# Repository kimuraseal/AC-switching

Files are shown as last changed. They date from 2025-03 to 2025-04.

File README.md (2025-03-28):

# 4CH AC, 2CH DC Switching and ZCD
The circuit consist of 
- Four optoisolated TRIAC switching circuit.
  Two channels being zero cross switched and other two being random phase switched.
- Two optoisolated MOSFET switching circuit.
  Capable of High speed operations.
- Zero Cross Detector.

# 4CH AC、2CH DC スイッチングおよびZCD
この回路は以下の構成になっています。
- 光アイソレーション付きTRIACスイッチング回路（4系統）
  2つはゼロクロススイッチング
  2つはランダムフェーズスイッチング
- 光アイソレーション付きMOSFETスイッチング回路（2系統）
  高速動作が可能
- ゼロクロス検出回路

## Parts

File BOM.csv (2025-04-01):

Country of Origin may be different at time of shipment.
The HTSUS and ECCN information shown is for informational purposes only and is not a representation or warranty as to the accuracy or reliability of these classifications. All information is provided "as is" and is subject to change without notice. Any use made of the information provided is without recourse to Digi-Key and at the user's risk.
Index | Manufacturer Part Number | Manufacturer Name | Description | Availability | Stock Status | Attrition % | Requested Quantity 1 | Pack Quantity 1 | Pack Type 1 | Digi-Key Part Number 1 | Unit Price 1 | Extended Price 1 | Minimum Order Quantity 1 | Customer Reference | Requested Part Number | Lead Weeks | Datasheet | Reference Designator | US Import Tariff | Note | Part Status | RoHS Status | REACH Status | Moisture Sensitivity Level (MSL) | ECCN | HTSUS | Country of Origin | Environmental Information | Original Part numbers | Unit of Measure | Image | Product Notes
1 | G800W268018EU | Amphenol ICC (Commercial Products) | PIN HEADER 2.54MM PITCH STR,1X40 | 1,288 | In Stock |  | 2 | 2 | Bag | 664-G800W268018EU-ND | 99.00000 | ¥198 | 1 |  | G800W268018EU | 10 | https://cdn.amphenol-cs.com/media/wysiwyg/files/drawing/g800wxxxxxxeu_1.pdf |  | - |  | Active | ROHS3 Compliant |  | Not Applicable | EAR99 | 8536.69.4040 | China |  | G800W268018EU | EACH | https://mm.digikey.com/Volume0/opasdata/d220001/derivates/6/001/148/493/G800W268018EU_web%28640x640%29.jpg
2 | PZT3904T1G | onsemi | TRANS NPN 40V 0.2A SOT223 | 21,926 | In Stock |  | 20 | 20 | Cut Tape (CT) | PZT3904T1GOSCT-ND | 55.40000 | ¥1,108 | 1 |  | PZT3904T1G | 14 | https://www.onsemi.com/pdf/datasheet/pzt3904t1-d.pdf |  | - |  | Active | ROHS3 Compliant | REACH Unaffected | 1 (Unlimited) | EAR99 | 8541.29.0075 | Malaysia | https://www.onsemi.com/site/pdf/RoHS-statement.pdf|https://www.onsemi.com/PowerSolutions/MaterialComposition.do?export=pdf&opnId=PZT3904T1G | SPZT3904T1G | EACH | https://mm.digikey.com/Volume0/opasdata/d220001/medias/images/6285/488%7E318E-04%7EST%7E4.jpg
3 | TLV1117-33CDCYR | Texas Instruments | IC REG LIN 3.3V 800MA SOT-223-4 | 9,822 | In Stock |  | 3 | 3 | Cut Tape (CT) | 296-21112-1-ND | 63.00000 | ¥189 | 1 |  | TLV1117-33CDCYR | 6 | https://www.ti.com/general/docs/suppproductinfo.tsp?distId=10 |  | - |  | Active | ROHS3 Compliant | REACH Unaffected | 2 (1 Year) | EAR99 | 8542.39.0060 | China |  | NCP1117ST33T3G | EACH | https://mm.digikey.com/Volume0/opasdata/d220001/medias/images/6222/296%7E4202506%7EDCY%7E4.jpg
4 | 691137710002 | Würth Elektronik | TERM BLK 2POS SIDE ENTRY 5MM PCB | 20,290 | In Stock |  | 12 | 12 | Box | 732-10955-ND | 51.20000 | ¥614 | 1 |  | 691137710002 | 19 | https://www.we-online.com/katalog/datasheet/691137710002.pdf |  | - |  | Active | ROHS3 Compliant | REACH Unaffected | Not Applicable | EAR99 | 8536.90.4000 | Italy | https://mm.digikey.com/Volume0/opasdata/d220001/medias/docus/744/Certificate_of_Compliance_ROHS.pdf | 6.91138E+11 | EACH | https://mm.digikey.com/Volume0/opasdata/d220001/medias/images/2284/MFG_691137710002_View2.jpg
5 | T1635-600G-TR | STMicroelectronics | TRIAC ALTERNISTOR 600V 16A D2PAK | 40,354 | In Stock |  | 10 | 10 | Cut Tape (CT) | 497-6594-1-ND | 169.40000 | ¥1,694 | 1 |  | T1635-600G-TR | 15 | https://www.st.com/content/ccc/resource/technical/document/datasheet/67/06/bc/c9/35/8e/4f/ea/CD00002265.pdf/files/CD00002265.pdf/jcr:content/translations/en.C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 |  | - |  | Active | ROHS3 Compliant | REACH Unaffected | 1 (Unlimited) | EAR99 | 8541.30.0080 | China |  | T1635-600G-TR | EACH | https://mm.digikey.com/Volume0/opasdata/d220001/medias/images/2435/D%C2%B2Pak%2CTO-263_418AA-01.jpg
6 | MOC3052M | onsemi | OPTOISOLTR 4.17KV TRIAC 1CH 6DIP | 5,330 | In Stock |  | 6 | 6 | Tube | MOC3052M-ND | 168.00000 | ¥1,008 | 1 |  | MOC3052M-ND | 8 | https://www.onsemi.com/pdf/datasheet/moc3052m-d.pdf |  | - |  | Active | ROHS3 Compliant | REACH Unaffected | Not Applicable | EAR99 | 8541.49.8000 | Thailand | https://www.onsemi.com/site/pdf/RoHS-statement.pdf|https://www.onsemi.com/PowerSolutions/MaterialComposition.do?export=pdf&opnId=MOC3052M | MOC3052M-ND | EACH | https://mm.digikey.com/Volume0/opasdata/d220001/medias/images/2438/46-6-DIP%20WHITE.jpg
7 | MOC3062M | onsemi | OPTOISOLTR 4.17KV TRIAC 1CH 6DIP | 3,921 | In Stock |  | 6 | 6 | Tube | MOC3062M-ND | 202.00000 | ¥1,212 | 1 |  | MOC3062M | 8 | https://www.onsemi.com/pdf/datasheet/moc3163m-d.pdf |  | - |  | Active | ROHS3 Compliant | REACH Unaffected | Not Applicable | EAR99 | 8541.49.8000 | South Korea | https://www.onsemi.com/site/pdf/RoHS-statement.pdf|https://www.onsemi.com/PowerSolutions/MaterialComposition.do?export=pdf&opnId=MOC3062M | MOC3062M | EACH | https://mm.digikey.com/Volume0/opasdata/d220001/medias/images/969/MOC3062M.JPG
8 | ERZ-V10D201 | Panasonic Electronic Components | VARISTOR 200V 3.5KA DISC 11.5MM | 2,210 | In Stock |  | 10 | 10 | Bulk | P7205-ND | 66.50000 | ¥665 | 1 |  | ERZ-V10D201 | 18 | https://industrial.panasonic.com/ww/products/pt/surge-components/models/ERZV10D201 |  | - |  | Active | ROHS3 Compliant | REACH Unaffected | Not Applicable | EAR99 | 8533.40.4000 | Indonesia |  | ERZ-V10D201 | EACH | https://mm.digikey.com/Volume0/opasdata/d220001/medias/images/2403/D10%2C%2014%20V%20Series.jpg
9 | B32682A6222K000 | EPCOS - TDK Electronics | CAP FILM 2200PF 10% 630VDC RAD | 1,836 | In Stock |  | 10 | 10 | Bulk | 495-7310-ND | 89.10000 | ¥891 | 1 |  | B32682A6222K000 | 10 | https://product.tdk.com/en/system/files |  | - |  | Active | ROHS3 Compliant | REACH Unaffected | Not Applicable | EAR99 | 8532.25.0070 | China | https://www.tdk-electronics.tdk.com/download/2078174/66ff23f8bbbac65cb7b31f8fa69f2b53/reach-rohs-declaration.pdf|https://www.tdk-electronics.tdk.com/en/180310/company/sustainability/environmental-protection/reach | B32682A6222K000 | EACH | https://mm.digikey.com/Volume0/opasdata/d220001/medias/images/909/B32682-Series.jpg
10 | RC1206FR-10150RL | YAGEO | RES 150 OHM 1% 1/4W 1206 | 18,000 | In Stock |  | 30 | 30 | Cut Tape (CT) | 13-RC1206FR-10150RLCT-ND | 3.00000 | ¥90 | 1 |  | RC1206FR-10150RL | 18 | https://www.yageo.com/upload/media/product/products/datasheet/rchip/PYu-RC_Group_51_RoHS_L_12.pdf |  | - |  | Active | ROHS3 Compliant | REACH Unaffected | 1 (Unlimited) | EAR99 | 8533.21.0030 | Taiwan | https://www.yageo.com/en/Download/Index/certificates#rchip | RC1206FR-10150RL | EACH | https://mm.digikey.com/Volume0/opasdata/d220001/medias/images/4842/Yageo-0603.jpg
11 | RC1206FR-10390RL | YAGEO | RES 390 OHM 1% 1/4W 1206 | 5,525 | In Stock |  | 30 | 30 | Cut Tape (CT) | 13-RC1206FR-10390RLCT-ND | 6.40000 | ¥192 | 1 |  | RC1206FR-10390RL | 18 | https://www.yageo.com/upload/media/product/products/datasheet/rchip/PYu-RC_Group_51_RoHS_L_12.pdf |  | - |  | Active | ROHS3 Compliant | REACH Unaffected | 1 (Unlimited) | EAR99 | 8533.21.0030 | Taiwan | https://www.yageo.com/en/Download/Index/certificates#rchip | RC1206FR-10390RL | EACH | https://mm.digikey.com/Volume0/opasdata/d220001/medias/images/4842/Yageo-0603.jpg
12 | RC1218JK-0751RL | YAGEO | RES 51 OHM 5% 1W 1812 WIDE | 7,379 | In Stock |  | 10 | 10 | Cut Tape (CT) | 13-RC1218JK-0751RLCT-ND | 22.50000 | ¥225 | 1 |  | RC1218JK-0751RL | 18 | https://www.yageo.com/upload/media/product/products/datasheet/rchip/PYu-RC_Group_51_RoHS_L_12.pdf |  | - |  | Active | ROHS3 Compliant | REACH Unaffected | 1 (Unlimited) | EAR99 | 8533.21.0030 | Taiwan | https://www.yageo.com/en/Download/Index/certificates#rchip | RC1218JK-0751RL | EACH | https://mm.digikey.com/Volume0/opasdata/d220001/medias/images/2289/Yageo-RC1218.jpg
13 | TLP250H(D4,F) | Toshiba Semiconductor and Storage | OPTOISO 3.75KV PUSH PULL 8-DIP | 438 | In Stock |  | 10 | 10 | Tube | TLP250H(D4F)-ND | 288.00000 | ¥2,880 | 1 |  | TLP250H(D4 F) | 12 | https://toshiba.semicon-storage.com/info/docget.jsp?did=13872&prodName=TLP250H |  | - |  | Active | ROHS3 Compliant | REACH Unaffected | Not Applicable | EAR99 | 8541.49.8000 | Japan |  | TLP250H(D4 F) | EACH | https://mm.digikey.com/Volume0/opasdata/d220001/medias/images/56/264%7E11-10C4%7E%7E8.jpg
14 | 4N35M | onsemi | OPTOISO 4.17KV TRANS W/BASE 6DIP | 4,296 | In Stock |  | 3 | 3 | Tube | 4N35MFS-ND | 103.00000 | ¥309 | 1 |  | 4N35MFS-ND | 8 | https://www.onsemi.com/pdf/datasheet/4n37m-d.pdf |  | - |  | Active | ROHS3 Compliant | REACH Unaffected | Not Applicable | EAR99 | 8541.49.8000 | Thailand | https://www.onsemi.com/site/pdf/RoHS-statement.pdf|https://www.onsemi.com/PowerSolutions/MaterialComposition.do?export=pdf&opnId=4N35M | 4N35MFS-ND | EACH | https://mm.digikey.com/Volume0/opasdata/d220001/medias/images/2438/46-6-DIP%20WHITE.jpg
15 | MDB6S | onsemi | BRIDGE RECT 1P 600V 1A 4MICRODIP | 29,697 | In Stock |  | 3 | 3 | Cut Tape (CT) | MDB6SFSCT-ND | 114.00000 | ¥342 | 1 |  | MDB6S | 18 | https://rocelec.widen.net/view/pdf/1nay6ifuuk/FAIRS45620-1.pdf?t.download=true&u=5oefqw |  | - |  | Active | ROHS3 Compliant | REACH Unaffected | 1 (Unlimited) | EAR99 | 8541.10.0080 | China | https://www.onsemi.com/site/pdf/RoHS-statement.pdf|https://www.onsemi.com/site/pdf/REACH-compliance-statement.pdf|https://www.onsemi.com/PowerSolutions/MaterialComposition.do?export=pdf&opnId=MDB6S | MDB6S | EACH | https://mm.digikey.com/Volume0/opasdata/d220001/medias/images/538/MDB6S.JPG
16 | SM5063 | Diotec Semiconductor | DIODE STANDARD 1000V 2A DO213AB | 4,598 | In Stock |  | 10 | 10 | Cut Tape (CT) | 4878-SM5063CT-ND | 27.10000 | ¥271 | 1 |  | SM5063 | 8 | https://diotec.com/request/datasheet/sm5059.pdf |  | - |  | Active | ROHS3 Compliant |  | 1 (Unlimited) | EAR99 | 8541.10.0080 | Slovenia | https://diotec.com/request/imds/p9_e.pdf | SM5063 | EACH | https://mm.digikey.com/Volume0/opasdata/d220001/derivates/6/003/224/470/MFG_4878%7EDO213AB%28MELF%29%7E%7E2_web%28640x640%29.jpg
17 | BZD27C10P-M3-08 | Vishay General Semiconductor - Diodes Division | DIODE ZENER 10V 800MW DO219AB | 11,700 | In Stock |  | 10 | 10 | Cut Tape (CT) | 112-BZD27C10P-M3-08CT-ND | 32.40000 | ¥324 | 1 |  | BZD27C10P-M3-08 | 16 | https://mm.digikey.com/Volume0/opasdata/d220001/medias/docus/2143/BZD27-M_Series.pdf |  | - |  | Active | ROHS3 Compliant | REACH Unaffected | 1 (Unlimited) | EAR99 | 8541.10.0050 | China |  | BZD27C10P-M3-08 | EACH | https://mm.digikey.com/Volume0/opasdata/d220001/medias/images/5789/112%7EDO219AB%28SMF%29%7E%7E2-View-2.jpg
18 | 50YXJ33M5X11 | Rubycon | CAP ALUM 33UF 20% 50V RADIAL TH | 5,178 | In Stock |  | 10 | 10 | Bulk | 1189-2323-ND | 29.70000 | ¥297 | 1 |  | 50YXJ33M5X11 | 20 | https://www.rubycon.co.jp/wp-content/uploads/catalog-aluminum/YXJ.pdf |  | - |  | Active | ROHS3 Compliant | REACH Unaffected | Not Applicable | EAR99 | 8532.22.0020 | Indonesia |  | 50YXF10MEFC5X11 | EACH | https://mm.digikey.com/Volume0/opasdata/d220001/medias/images/2595/YXJ%20Series%205x11.jpg
19 | B32529C6102M289 | EPCOS - TDK Electronics | CAP FILM 1000PF 20% 400VDC RAD | 15,998 | In Stock |  | 3 | 3 | Cut Tape (CT) | 495-B32529C6102M289CT-ND | 50.00000 | ¥150 | 1 |  | B32529C6102M289 | 7 | https://product.tdk.com/en/system/files |  | - |  | Active | ROHS3 Compliant | REACH Unaffected | Not Applicable | EAR99 | 8532.25.0070 | Brazil | https://www.tdk-electronics.tdk.com/download/2078174/66ff23f8bbbac65cb7b31f8fa69f2b53/reach-rohs-declaration.pdf|https://www.tdk-electronics.tdk.com/en/180310/company/sustainability/environmental-protection/reach | B32529C6102M289 | EACH | https://mm.digikey.com/Volume0/opasdata/d220001/medias/images/2586/MKT%20SERIES%208.0H%2C7.2L.jpg
20 | LTST-C150KGKT | Lite-On Inc. | LED GREEN CLEAR 1206 SMD | 368,310 | In Stock |  | 15 | 15 | Cut Tape (CT) | 160-1404-1-ND | 19.60000 | ¥294 | 1 |  | LTST-C150KGKT | 18 | https://optoelectronics.liteon.com/upload/download/DS22-2000-072/LTST-C150KGKT.pdf |  | - |  | Active | ROHS3 Compliant | REACH Unaffected | 3 (168 Hours) | EAR99 | 8541.41.0000 | China |  | LTST-C150KGKT | EACH | https://mm.digikey.com/Volume0/opasdata/d220001/medias/images/1055/LTST-C150TBKT%2CLTST-C150KAKT%2CLTST-C150KGKT.jpg
21 | LTST-C150KRKT | Lite-On Inc. | LED RED CLEAR 1206 SMD | 122,314 | In Stock |  | 15 | 15 | Cut Tape (CT) | 160-1405-1-ND | 19.60000 | ¥294 | 1 |  | LTST-C150KRKT | 18 | https://optoelectronics.liteon.com/upload/download/DS-22-99-0149/LTST-C150KRKT.pdf |  | - |  | Active | ROHS3 Compliant | REACH Unaffected | 3 (168 Hours) | EAR99 | 8541.41.0000 | China |  | LTST-C150KRKT | EACH | https://mm.digikey.com/Volume0/opasdata/d220001/medias/images/1062/LTST-C150KRKT%2CLTST-C150KSKT%2CLTST-C150KYKT.jpg
22 | RC1206FR-10180RL | YAGEO | RES 180 OHM 1% 1/4W 1206 | 25,517 | In Stock |  | 30 | 30 | Cut Tape (CT) | 13-RC1206FR-10180RLCT-ND | 6.40000 | ¥192 | 1 |  | RC1206FR-10180RL | 18 | https://www.yageo.com/upload/media/product/products/datasheet/rchip/PYu-RC_Group_51_RoHS_L_12.pdf |  | - |  | Active | ROHS3 Compliant | REACH Unaffected | 1 (Unlimited) | EAR99 | 8533.21.0030 | Taiwan | https://www.yageo.com/en/Download/Index/certificates#rchip | RC1206FR-10180RL | EACH | https://mm.digikey.com/Volume0/opasdata/d220001/medias/images/4842/Yageo-0603.jpg
23 | RC1206FR-10100RL | YAGEO | RES 100 OHM 1% 1/4W 1206 | 34,982 | In Stock |  | 30 | 30 | Cut Tape (CT) | 13-RC1206FR-10100RLCT-ND | 3.00000 | ¥90 | 1 |  | RC1206FR-10100RL | 18 | https://www.yageo.com/upload/media/product/products/datasheet/rchip/PYu-RC_Group_51_RoHS_L_12.pdf |  | - |  | Active | ROHS3 Compliant | REACH Unaffected | 1 (Unlimited) | EAR99 | 8533.21.0030 | Taiwan | https://www.yageo.com/en/Download/Index/certificates#rchip | RC1206FR-10100RL | EACH | https://mm.digikey.com/Volume0/opasdata/d220001/medias/images/4842/Yageo-0603.jpg
24 | RC1206FR-101KL | YAGEO | RES 1K OHM 1% 1/4W 1206 | 11,207 | In Stock |  | 10 | 10 | Cut Tape (CT) | 13-RC1206FR-101KLCT-ND | 3.00000 | ¥30 | 1 |  | RC1206FR-101KL | 18 | https://www.yageo.com/upload/media/product/products/datasheet/rchip/PYu-RC_Group_51_RoHS_L_12.pdf |  | - |  | Active | ROHS3 Compliant | REACH Unaffected | 1 (Unlimited) | EAR99 | 8533.21.0030 | Taiwan | https://www.yageo.com/en/Download/Index/certificates#rchip | RC1206FR-101KL | EACH | https://mm.digikey.com/Volume0/opasdata/d220001/medias/images/4842/Yageo-0603.jpg
25 | RC1206FR-103K3L | YAGEO | RES 3.3K OHM 1% 1/4W 1206 | 21,215 | In Stock |  | 10 | 10 | Cut Tape (CT) | 13-RC1206FR-103K3LCT-ND | 2.20000 | ¥22 | 1 |  | RC1206FR-103K3L | 18 | https://www.yageo.com/upload/media/product/products/datasheet/rchip/PYu-RC_Group_51_RoHS_L_12.pdf |  | - |  | Active | ROHS3 Compliant | REACH Unaffected | 1 (Unlimited) | EAR99 | 8533.21.0030 | Taiwan | https://www.yageo.com/en/Download/Index/certificates#rchip | RC1206FR-103K3L | EACH | https://mm.digikey.com/Volume0/opasdata/d220001/medias/images/4842/Yageo-0603.jpg
26 | RC1206FR-1010KL | YAGEO | RES 10K OHM 1% 1/4W 1206 | 28,383 | In Stock |  | 10 | 10 | Cut Tape (CT) | 13-RC1206FR-1010KLCT-ND | 3.30000 | ¥33 | 1 |  | RC1206FR-1010KL | 18 | https://www.yageo.com/upload/media/product/products/datasheet/rchip/PYu-RC_Group_51_RoHS_L_12.pdf |  | - |  | Active | ROHS3 Compliant | REACH Unaffected | 1 (Unlimited) | EAR99 | 8533.21.0030 | Taiwan | https://www.yageo.com/en/Download/Index/certificates#rchip | RC1206FR-1010KL | EACH | https://mm.digikey.com/Volume0/opasdata/d220001/medias/images/4842/Yageo-0603.jpg
27 | RC1206FR-1047KL | YAGEO | RES 47K OHM 1% 1/4W 1206 | 26,145 | In Stock |  | 10 | 10 | Cut Tape (CT) | 13-RC1206FR-1047KLCT-ND | 3.00000 | ¥30 | 1 |  | RC1206FR-1047KL | 18 | https://www.yageo.com/upload/media/product/products/datasheet/rchip/PYu-RC_Group_51_RoHS_L_12.pdf |  | - |  | Active | ROHS3 Compliant | REACH Unaffected | 1 (Unlimited) | EAR99 | 8533.21.0030 | Taiwan | https://www.yageo.com/en/Download/Index/certificates#rchip | RC1206FR-1047KL | EACH | https://mm.digikey.com/Volume0/opasdata/d220001/medias/images/4842/Yageo-0603.jpg
28 | 691137710003 | Würth Elektronik | TERM BLK 3POS SIDE ENTRY 5MM PCB | 1,757 | In Stock |  | 10 | 10 | Box | 732-10956-ND | 82.50000 | ¥825 | 1 |  | 691137710003 | 19 | https://www.we-online.com/katalog/datasheet/691137710003.pdf |  | - |  | Active | ROHS3 Compliant | REACH Unaffected | Not Applicable | EAR99 | 8536.90.4000 | Italy | https://mm.digikey.com/Volume0/opasdata/d220001/medias/docus/744/Certificate_of_Compliance_ROHS.pdf | 6.91138E+11 | EACH | https://mm.digikey.com/Volume0/opasdata/d220001/medias/images/2357/MFG_691137710003_View2.jpg
29 | RC1218JK-07100RL | YAGEO | RES 100 OHM 5% 1W 1812 WIDE | 9,047 | In Stock |  | 10 | 10 | Cut Tape (CT) | 13-RC1218JK-07100RLCT-ND | 14.70000 | ¥147 | 1 |  | RC1218JK-07100RL | 18 | https://www.yageo.com/upload/media/product/products/datasheet/rchip/PYu-RC_Group_51_RoHS_L_12.pdf |  | - |  | Active | ROHS3 Compliant | REACH Unaffected | 1 (Unlimited) | EAR99 | 8533.21.0030 | Taiwan |  | RC1218JK-07100RL | EACH | https://mm.digikey.com/Volume0/opasdata/d220001/medias/images/2289/Yageo-RC1218.jpg | Non Cancellable Non Returnable.
30 | STD7NK40ZT4 | STMicroelectronics | MOSFET N-CH 400V 5.4A DPAK | 4,690 | In Stock |  | 10 | 10 | Cut Tape (CT) | 497-6565-1-ND | 215.60000 | ¥2,156 | 1 |  | STD7NK40ZT4 | 13 | https://www.st.com/content/ccc/resource/technical/document/datasheet/67/d1/ab/b4/95/b0/4c/33/CD00003040.pdf/files/CD00003040.pdf/jcr:content/translations/en.C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 |  | - |  | Active | ROHS3 Compliant | REACH Unaffected | 1 (Unlimited) | EAR99 | 8541.29.0095 | China |  | STD7NK40ZT4 | EACH | https://mm.digikey.com/Volume0/opasdata/d220001/medias/images/6256/497%7EDPAK%28TO252-3%29%7E%7E2.jpg
31 | NC191LT10 | Chip Quik Inc. | SMOOTH FLOW LOW TEMP SOLDER PAST | 74 | In Stock |  | 1 | 1 | Bulk | 315-NC191LT10-ND | 1,245.00000 | ¥1,245 | 1 |  | NC191LT10 | 4 | http://www.chipquik.com/datasheets/NC191LT10.pdf |  | - |  | Active | ROHS3 Compliant | REACH Unaffected | 1 (Unlimited) | EAR99 | 3810.10.0000 | Canada |  | NC191LT10 | EACH | https://mm.digikey.com/Volume0/opasdata/d220001/medias/images/57/MFG_NC191LT10.jpg
32 | NC191 | Chip Quik Inc. | SMOOTH FLOW TACK FLUX NO-CLEAN I | 555 | In Stock |  | 1 | 1 | Bulk | 315-NC191-ND | 1,558.00000 | ¥1,558 | 1 |  | NC191 | 4 | http://www.chipquik.com/datasheets/NC191.pdf |  | - |  | Active | ROHS3 Compliant | REACH Unaffected | 1 (Unlimited) | EAR99 | 3810.10.0000 | Canada |  | NC191 | EACH | https://mm.digikey.com/Volume0/opasdata/d220001/medias/images/57/MFG_NC191.jpg

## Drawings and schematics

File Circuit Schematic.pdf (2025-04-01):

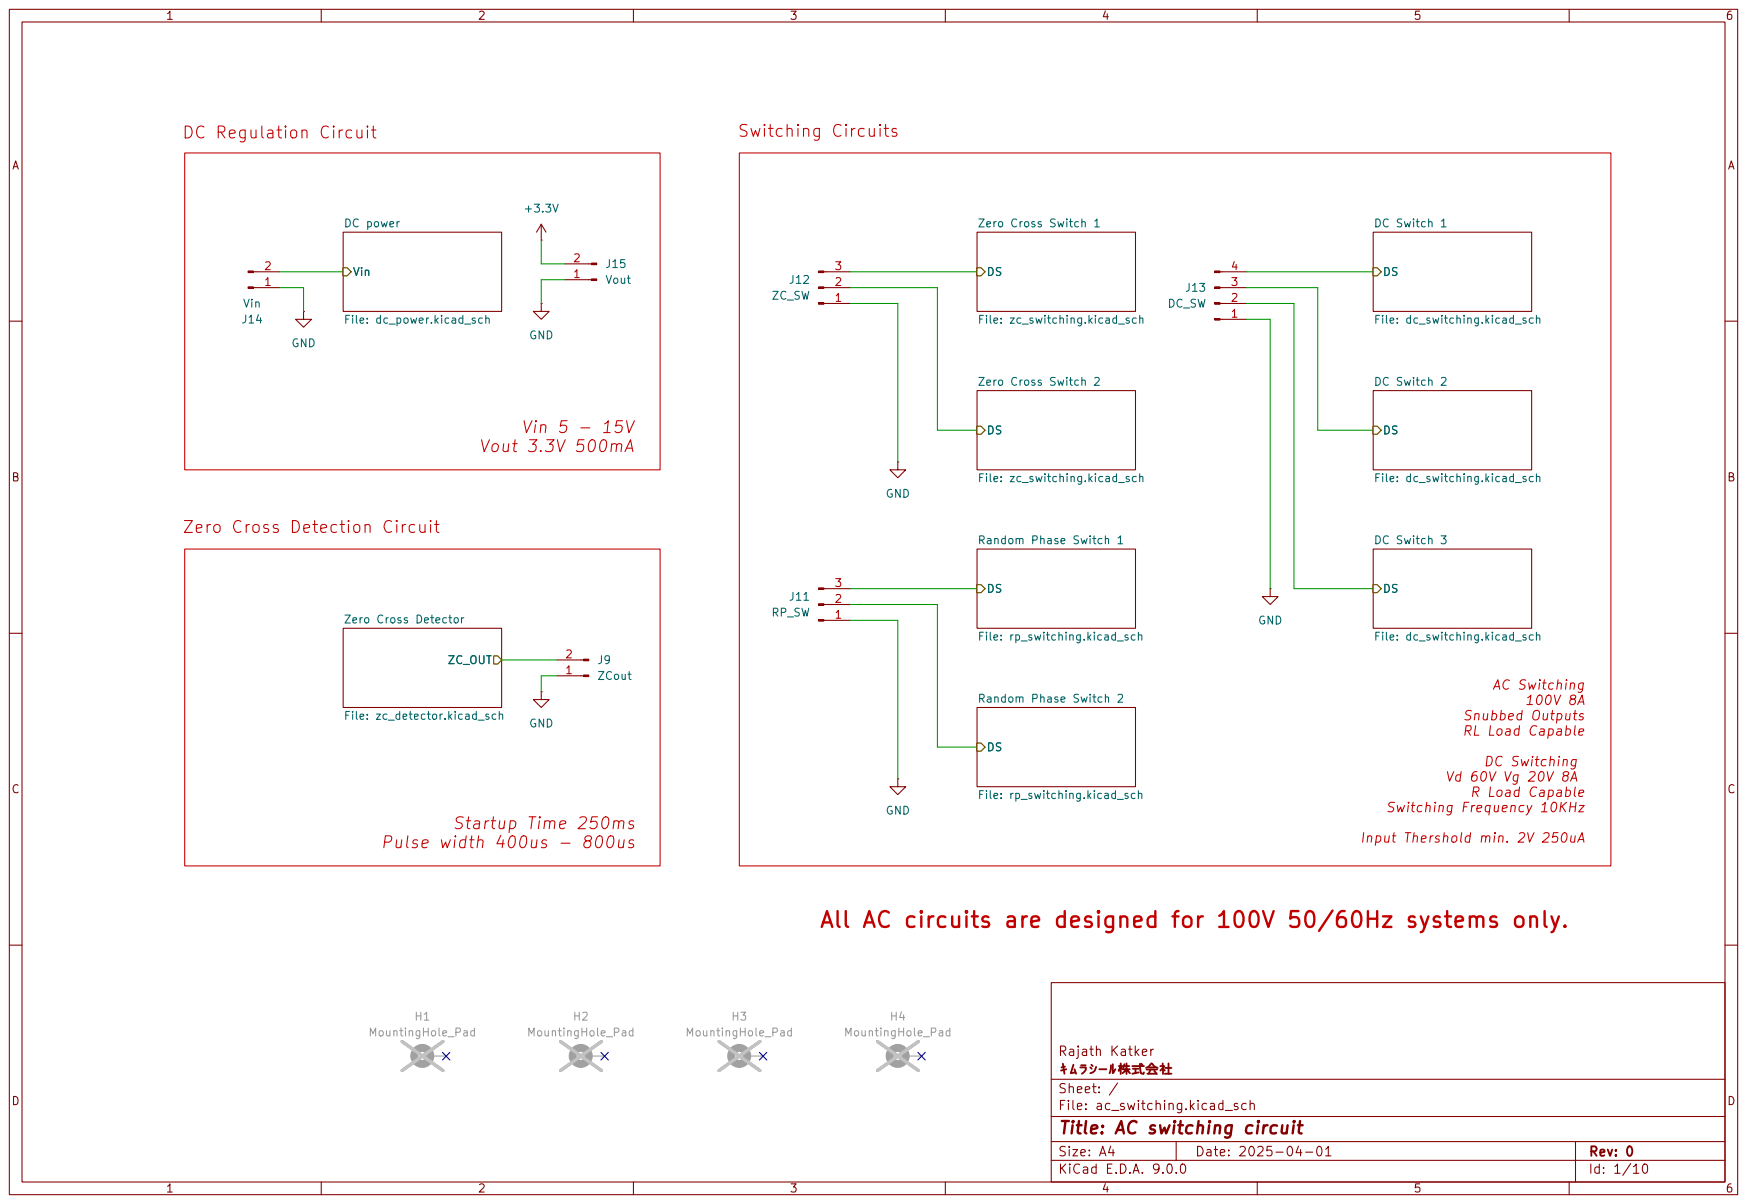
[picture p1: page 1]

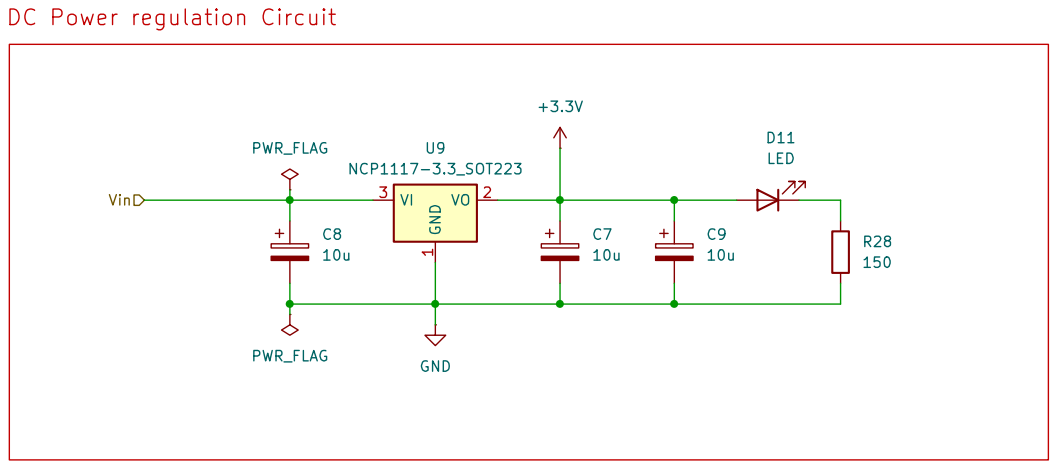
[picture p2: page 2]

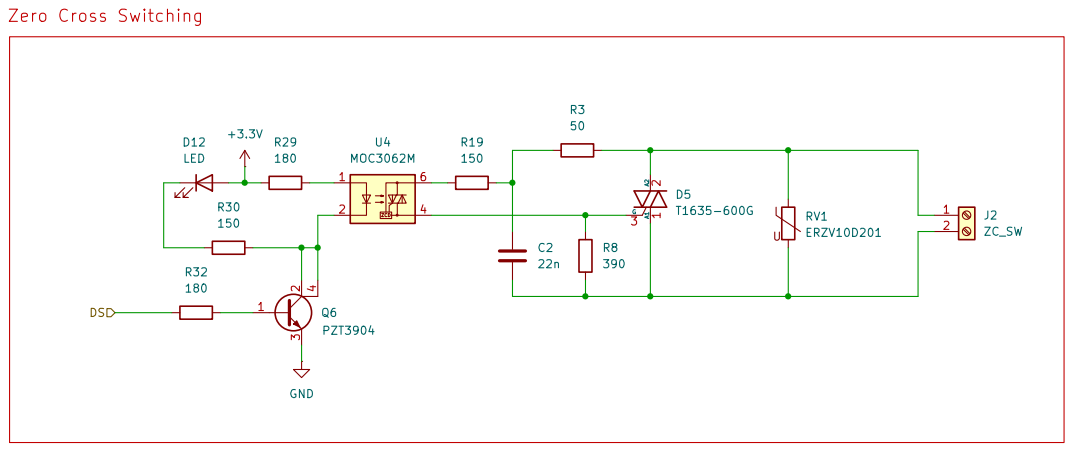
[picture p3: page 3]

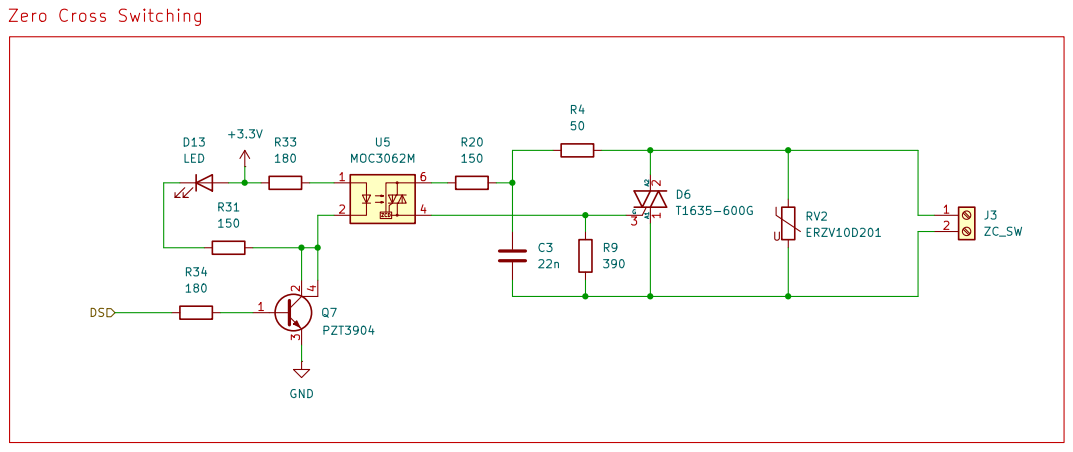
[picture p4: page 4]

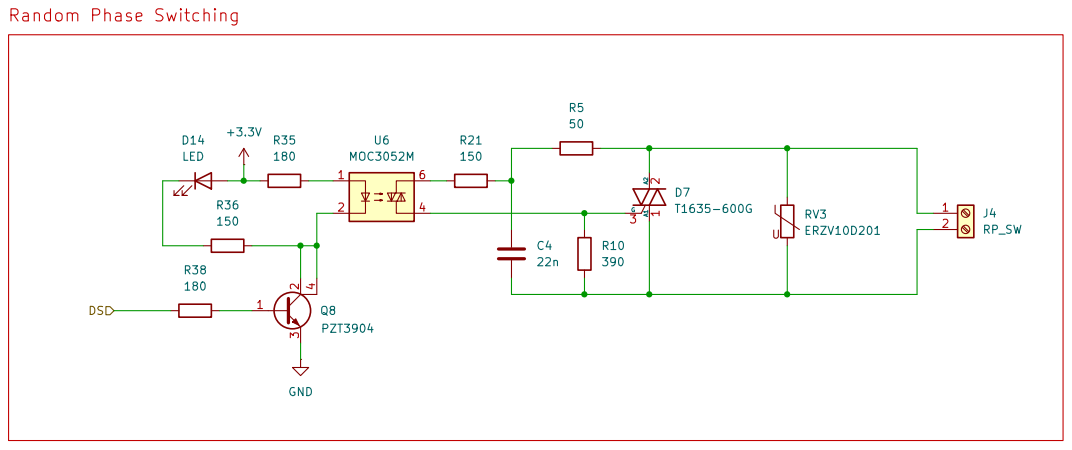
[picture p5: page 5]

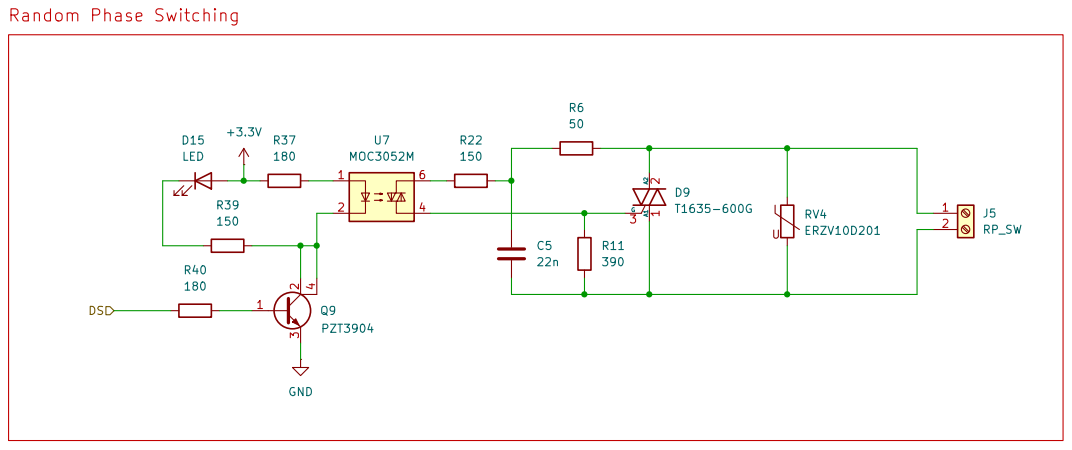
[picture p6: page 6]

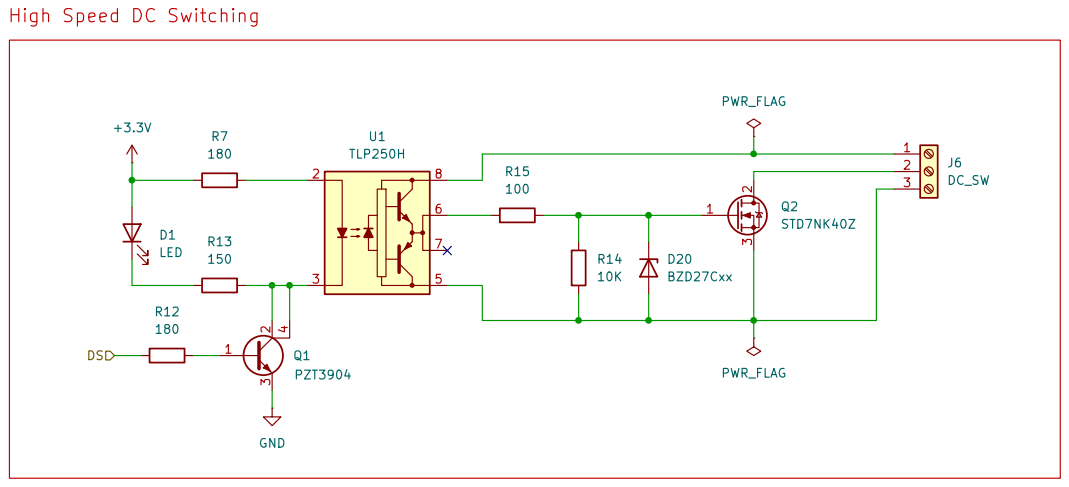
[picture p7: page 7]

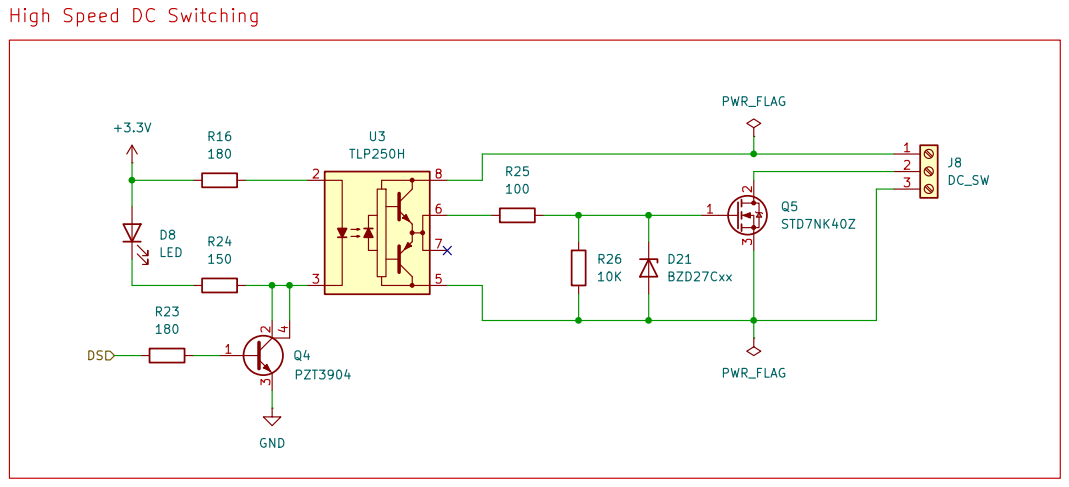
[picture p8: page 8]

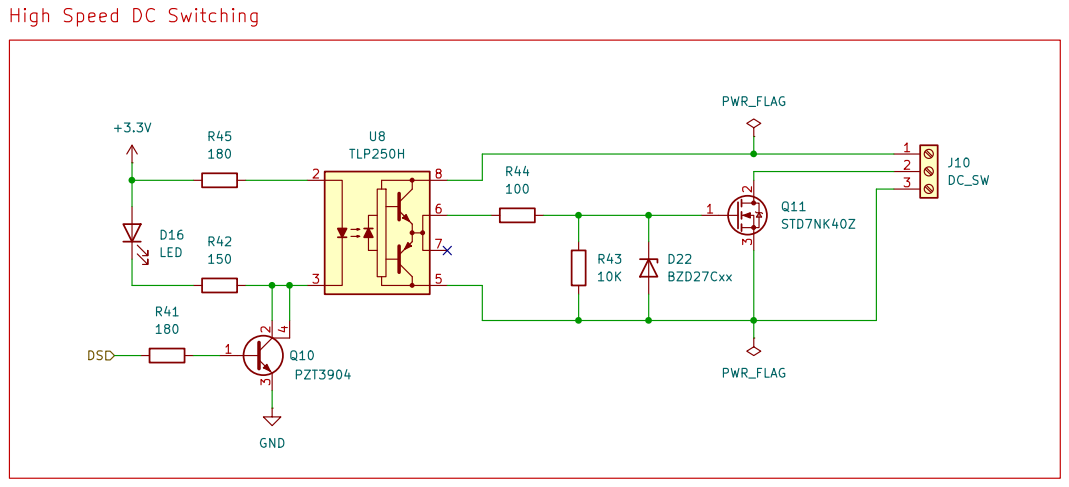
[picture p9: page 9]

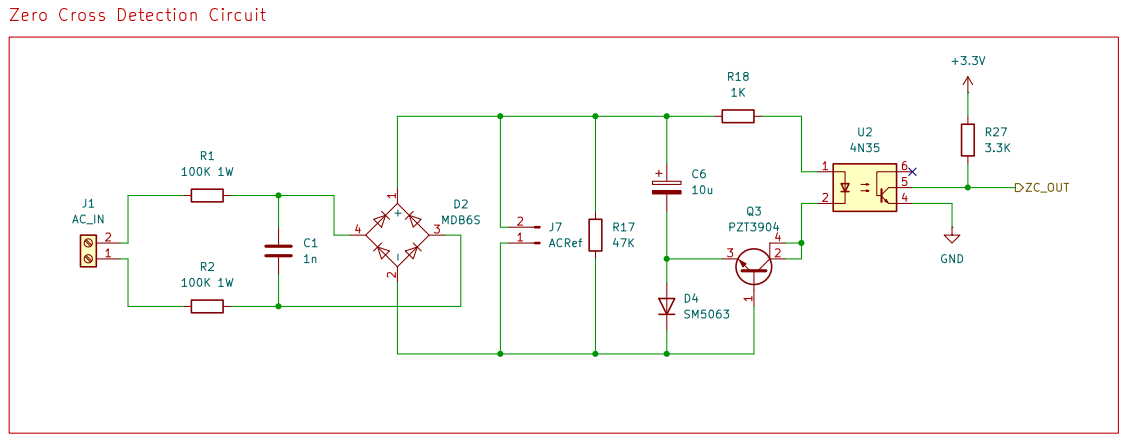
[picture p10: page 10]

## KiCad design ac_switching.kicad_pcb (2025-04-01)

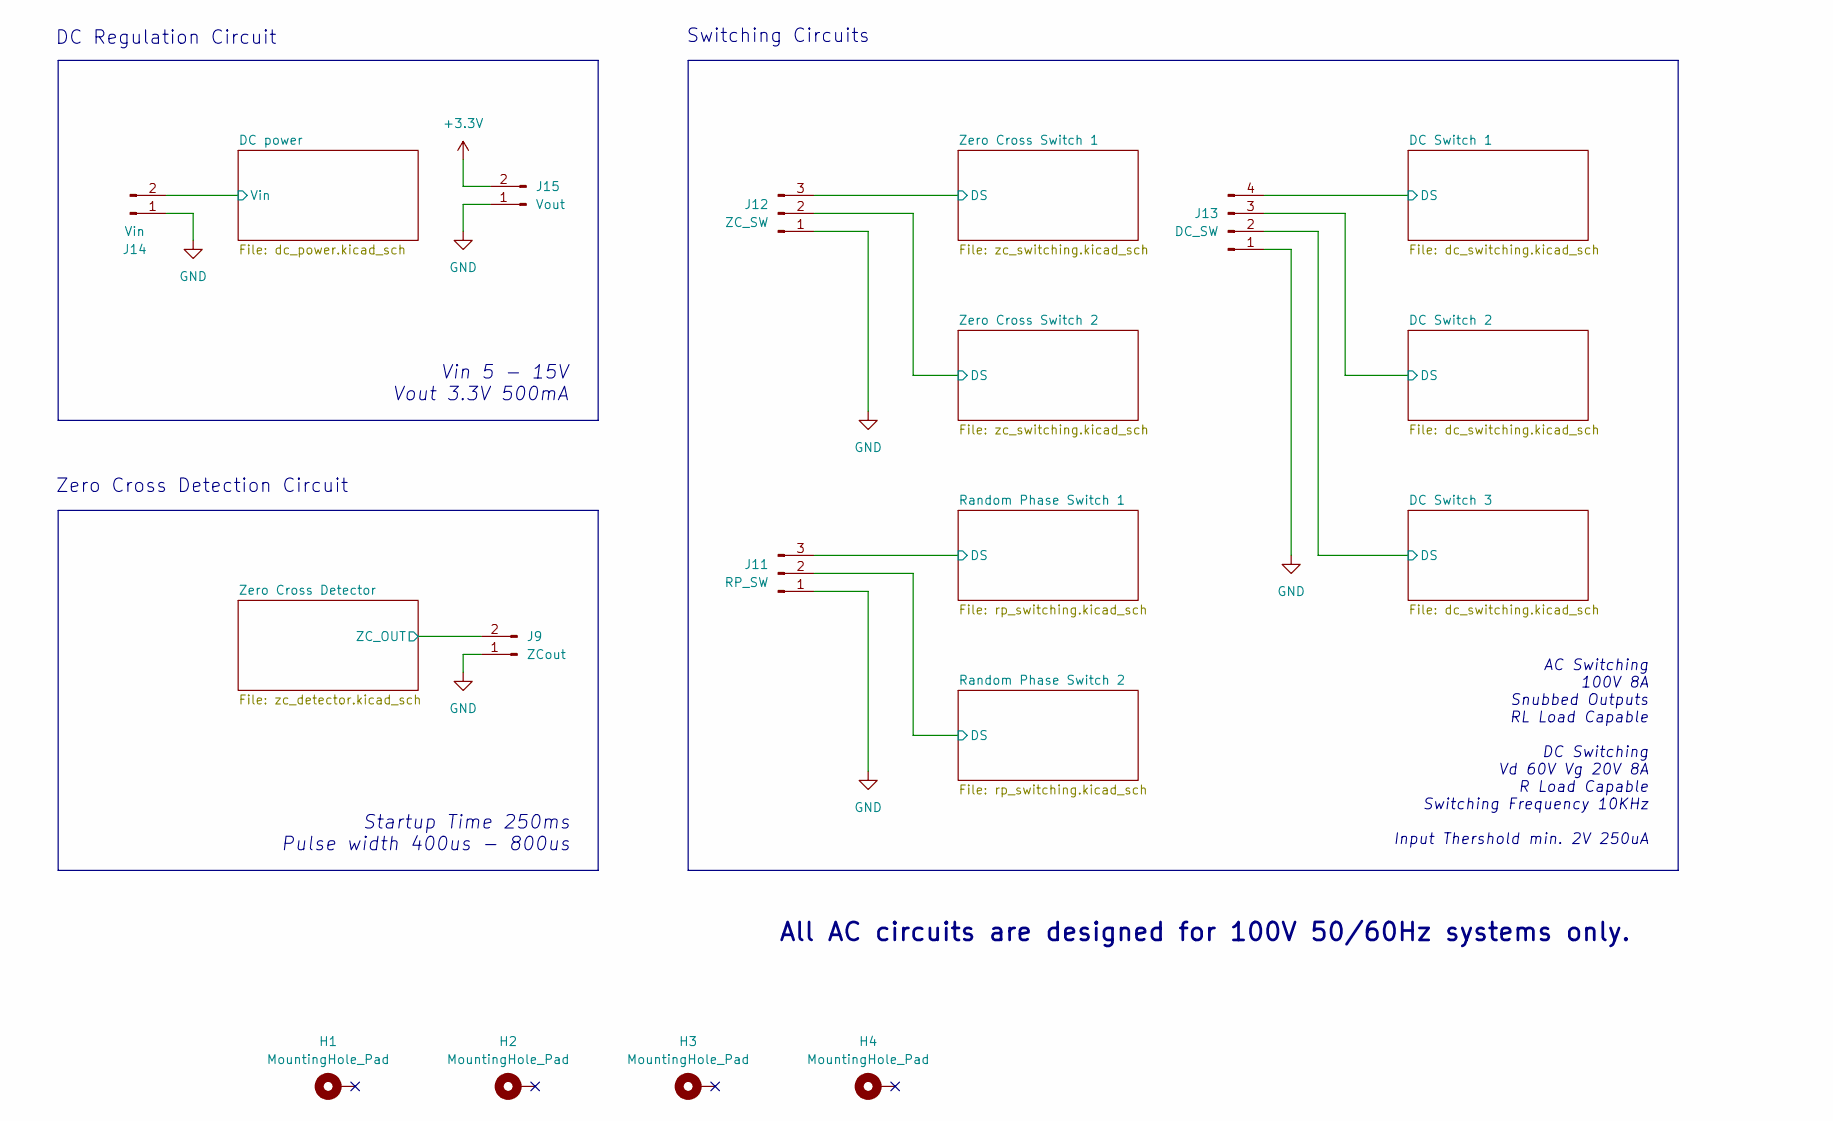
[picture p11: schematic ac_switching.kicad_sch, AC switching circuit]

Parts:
H1, H2, H3, H4: MountingHole_Pad; 3mm Mouting hole
J9: ZCout; PinSocket_1x02_P2.54mm_Vertical
J11: RP_SW; PinSocket_1x03_P2.54mm_Vertical
J12: ZC_SW; PinSocket_1x03_P2.54mm_Vertical
J13: DC_SW; PinSocket_1x04_P2.54mm_Vertical
J14: Vin; PinSocket_1x02_P2.54mm_Vertical
J15: Vout; PinSocket_1x02_P2.54mm_Vertical

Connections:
+3.3V: J15.2; also elsewhere on the board
/DC Switch 1/DS: J13.4; also elsewhere on the board
/DC Switch 2/DS: J13.3; also elsewhere on the board
/DC Switch 3/DS: J13.2; also elsewhere on the board
/DC power/Vin: J14.2; also elsewhere on the board
/Random Phase Switch 1/DS: J11.3; also elsewhere on the board
/Random Phase Switch 2/DS: J11.2; also elsewhere on the board
/Zero Cross Detector/ZC_OUT: J9.2; also elsewhere on the board
/Zero Cross Switch 1/DS: J12.3; also elsewhere on the board
/Zero Cross Switch 2/DS: J12.2; also elsewhere on the board
GND: J9.1, J11.1, J12.1, J13.1, J14.1, J15.1; also elsewhere on the board

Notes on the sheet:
Startup Time 250ms Pulse width 400us - 800us
Vin 5 - 15V Vout 3.3V 500mA
DC Regulation Circuit
AC Switching 100V 8A Snubbed Outputs RL Load Capable DC Switching Vd 60V Vg 20V 8A R Load Capable Switching Frequency 10KHz Input Thershold min. 2V 250uA
All AC circuits are designed for 100V 50/60Hz systems only.
Switching Circuits
Zero Cross Detection Circuit

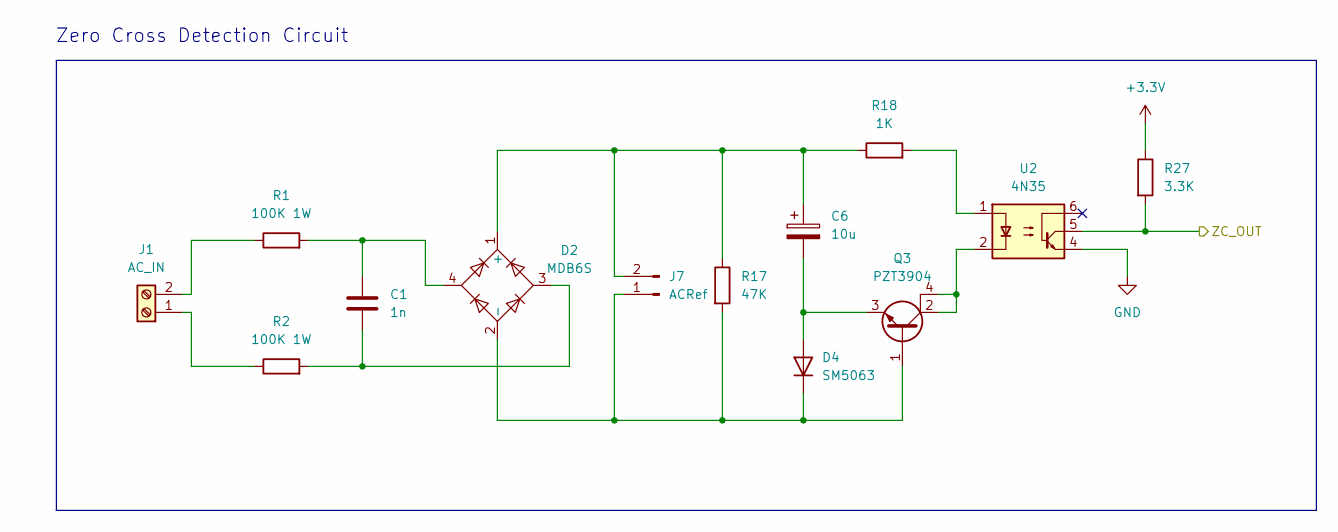
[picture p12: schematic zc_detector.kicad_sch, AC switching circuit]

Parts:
C1: 1n; TDK B32529C6102
C6: 10u; Rubycon YXF 50V 10uF
D2: MDB6S; TSSOP-4_4.4x5mm_P4mm
D4: SM5063; D_MELF
J1: AC_IN; TerminalBlock_bornier-2_P5.08mm
J7: ACRef; PinSocket_1x02_P2.54mm_Vertical
Q3: PZT3904; SOT-223
R1, R2: 100K 1W; Yageo RC_L 1218
R17: 47K; Yageo RC_L 1206
R18: 1K; Yageo RC_L 1206
R27: 3.3K; Yageo RC_L 1206
U2: 4N35; DIP-6_W7.62mm

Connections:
+3.3V: R27.1; also elsewhere on the board
/Zero Cross Detector/ZC_OUT: R27.2, U2.5; also elsewhere on the board
GND: U2.4; also elsewhere on the board
unnamed: C1.1, D2.4, R1.2
unnamed: C1.2, D2.3, R2.2
unnamed: C6.1, D2.1 (+), J7.2, R17.1, R18.1
unnamed: D2.2 (-), D4.1 (K), J7.1, Q3.1 (B), R17.2
unnamed: C6.2, D4.2 (A), Q3.3 (E)
unnamed: J1.1, R2.1
unnamed: J1.2, R1.1
unnamed: Q3.2 (C), Q3.4 (C), U2.2
unnamed: R18.2, U2.1

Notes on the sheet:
Zero Cross Detection Circuit

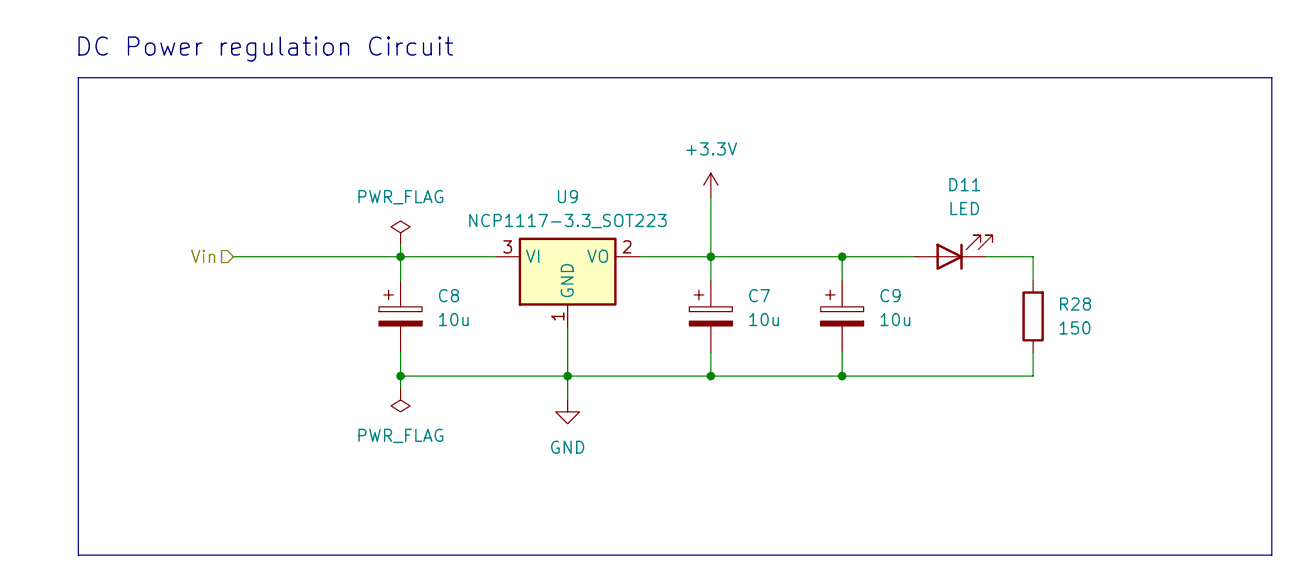
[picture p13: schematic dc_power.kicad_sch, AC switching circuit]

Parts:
C7, C8, C9: 10u; Rubycon YXF 50V 10uF
D11: LED; Lite On LTST-C150
R28: 150; Yageo RC_L 1206
U9: NCP1117-3.3_SOT223; SOT-223-3_TabPin2

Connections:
+3.3V: C7.1, C9.1, D11.2 (A), U9.2 (VO); also elsewhere on the board
/DC power/Vin: C8.1, U9.3 (VI); also elsewhere on the board
GND: C7.2, C8.2, C9.2, R28.1, U9.1 (GND); also elsewhere on the board
unnamed: D11.1 (K), R28.2

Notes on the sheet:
DC Power regulation Circuit

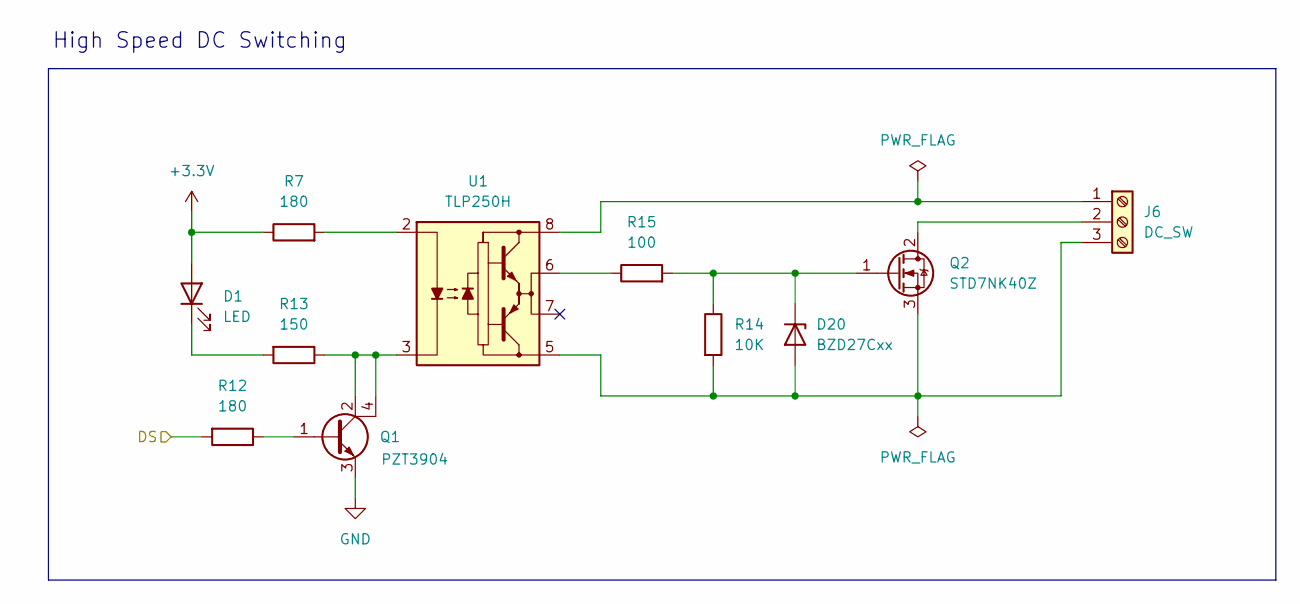
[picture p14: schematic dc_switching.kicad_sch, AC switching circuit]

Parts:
D1: LED; Lite On LTST-C150
D20: BZD27Cxx; D_SMF
J6: DC_SW; TerminalBlock_bornier-3_P5.08mm
Q1: PZT3904; SOT-223
Q2: STD7NK40Z; TO-252-2
R7, R12: 180; Yageo RC_L 1206
R13: 150; Yageo RC_L 1206
R14: 10K; Yageo RC_L 1206
R15: 100; Yageo RC_L 1206
U1: TLP250H; DIP-8_W7.62mm

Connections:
+3.3V: D1.2 (A), R7.1; also elsewhere on the board
/DC Switch 1/DS: R12.2; also elsewhere on the board
GND: Q1.3 (E); also elsewhere on the board
unnamed: D1.1 (K), R13.2
unnamed: D20.2 (A), J6.3, Q2.3 (S), R14.2, U1.5 (VEE)
unnamed: D20.1 (K), Q2.1 (G), R14.1, R15.2
unnamed: J6.1, U1.8 (VCC)
unnamed: J6.2, Q2.2 (D)
unnamed: Q1.1 (B), R12.1
unnamed: R15.1, U1.6 (VO)
unnamed: R7.2, U1.2 (A)
unnamed: Q1.2 (C), Q1.4 (C), R13.1, U1.3 (C)

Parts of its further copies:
D8, D16: LED; Lite On LTST-C150
D21, D22: BZD27Cxx; D_SMF
J8, J10: DC_SW; TerminalBlock_bornier-3_P5.08mm
Q4, Q10: PZT3904; SOT-223
Q5, Q11: STD7NK40Z; TO-252-2
R16, R23, R41, R45: 180; Yageo RC_L 1206
R24, R42: 150; Yageo RC_L 1206
R25, R44: 100; Yageo RC_L 1206
R26, R43: 10K; Yageo RC_L 1206
U3, U8: TLP250H; DIP-8_W7.62mm

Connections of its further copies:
+3.3V: D8.2 (A), D16.2 (A), R16.1, R45.1; also elsewhere on the board
/DC Switch 2/DS: R23.2; also elsewhere on the board
/DC Switch 3/DS: R41.2; also elsewhere on the board
GND: Q4.3 (E), Q10.3 (E); also elsewhere on the board
unnamed: D8.1 (K), R24.2
unnamed: D16.1 (K), R42.2
unnamed: D21.2 (A), J8.3, Q5.3 (S), R26.2, U3.5 (VEE)
unnamed: D21.1 (K), Q5.1 (G), R25.2, R26.1
unnamed: D22.2 (A), J10.3, Q11.3 (S), R43.2, U8.5 (VEE)
unnamed: D22.1 (K), Q11.1 (G), R43.1, R44.2
unnamed: J8.1, U3.8 (VCC)
unnamed: J8.2, Q5.2 (D)
unnamed: J10.1, U8.8 (VCC)
unnamed: J10.2, Q11.2 (D)
unnamed: Q4.1 (B), R23.1
unnamed: Q10.1 (B), R41.1
unnamed: R25.1, U3.6 (VO)
unnamed: R44.1, U8.6 (VO)
unnamed: R16.2, U3.2 (A)
unnamed: Q4.2 (C), Q4.4 (C), R24.1, U3.3 (C)
unnamed: R45.2, U8.2 (A)
unnamed: Q10.2 (C), Q10.4 (C), R42.1, U8.3 (C)

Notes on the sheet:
High Speed DC Switching

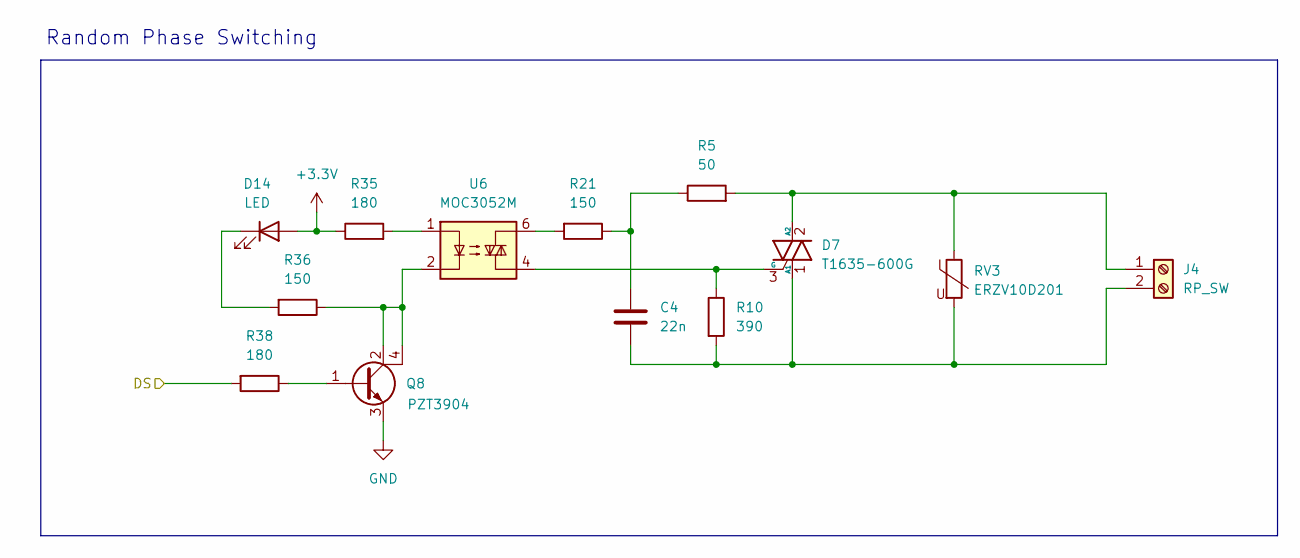
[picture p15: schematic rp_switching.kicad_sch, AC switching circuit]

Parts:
C4: 22n; TDK B32682A4223
D7: T1635-600G; ST MIcroelectronics T16xx
D14: LED; Lite On LTST-C150
J4: RP_SW; TerminalBlock_bornier-2_P5.08mm
Q8: PZT3904; SOT-223
R5: 50; Yageo RC_L 1218
R10: 390; Yageo RC_L 1206
R21, R36: 150; Yageo RC_L 1206
R35, R38: 180; Yageo RC_L 1206
RV3: ERZV10D201; Panasonic ERZV10D201
U6: MOC3052M; DIP-6_W7.62mm

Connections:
+3.3V: D14.2 (A), R35.1; also elsewhere on the board
/Random Phase Switch 1/DS: R38.2; also elsewhere on the board
GND: Q8.3 (E); also elsewhere on the board
unnamed: C4.1, R5.1, R21.1
unnamed: C4.2, D7.1 (A1), J4.2, R10.2, RV3.2
unnamed: D7.2 (A2), J4.1, R5.2, RV3.1
unnamed: D7.3 (G), R10.1, U6.4
unnamed: D14.1 (K), R36.2
unnamed: Q8.1 (B), R38.1
unnamed: Q8.2 (C), Q8.4 (C), R36.1, U6.2
unnamed: R21.2, U6.6
unnamed: R35.2, U6.1

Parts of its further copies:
C5: 22n; TDK B32682A4223
D9: T1635-600G; ST MIcroelectronics T16xx
D15: LED; Lite On LTST-C150
J5: RP_SW; TerminalBlock_bornier-2_P5.08mm
Q9: PZT3904; SOT-223
R6: 50; Yageo RC_L 1218
R11: 390; Yageo RC_L 1206
R22, R39: 150; Yageo RC_L 1206
R37, R40: 180; Yageo RC_L 1206
RV4: ERZV10D201; Panasonic ERZV10D201
U7: MOC3052M; DIP-6_W7.62mm

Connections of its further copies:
+3.3V: D15.2 (A), R37.1; also elsewhere on the board
/Random Phase Switch 2/DS: R40.2; also elsewhere on the board
GND: Q9.3 (E); also elsewhere on the board
unnamed: C5.1, R6.1, R22.1
unnamed: C5.2, D9.1 (A1), J5.2, R11.2, RV4.2
unnamed: D9.2 (A2), J5.1, R6.2, RV4.1
unnamed: D9.3 (G), R11.1, U7.4
unnamed: D15.1 (K), R39.2
unnamed: Q9.1 (B), R40.1
unnamed: Q9.2 (C), Q9.4 (C), R39.1, U7.2
unnamed: R22.2, U7.6
unnamed: R37.2, U7.1

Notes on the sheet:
Random Phase Switching

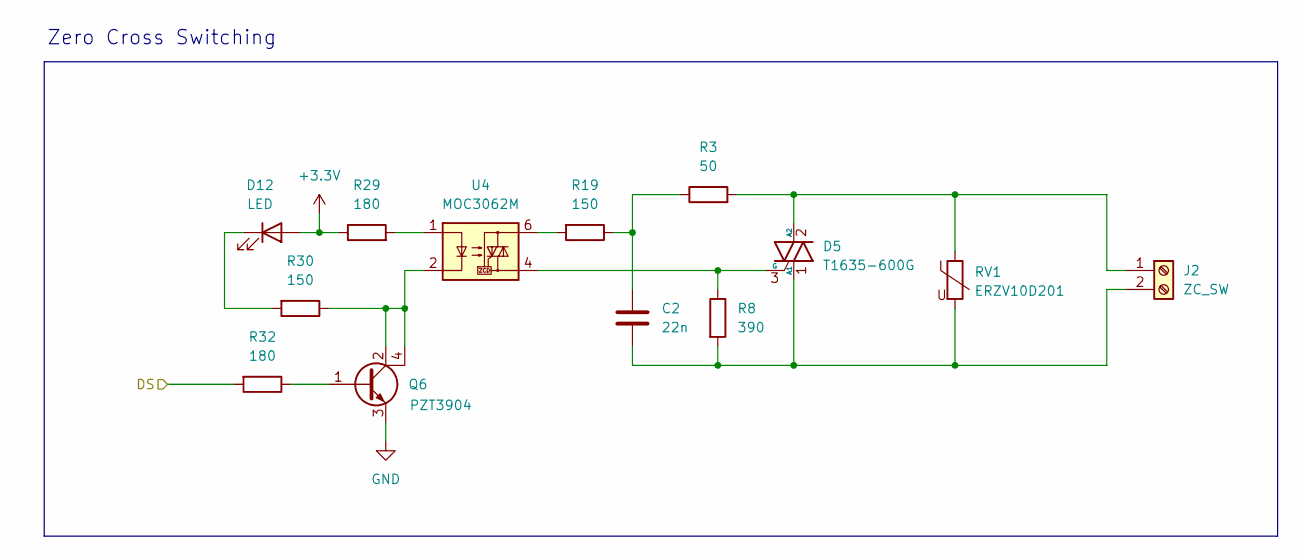
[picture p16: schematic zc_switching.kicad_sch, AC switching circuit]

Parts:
C2: 22n; TDK B32682A4223
D5: T1635-600G; ST MIcroelectronics T16xx
D12: LED; Lite On LTST-C150
J2: ZC_SW; TerminalBlock_bornier-2_P5.08mm
Q6: PZT3904; SOT-223
R3: 50; Yageo RC_L 1218
R8: 390; Yageo RC_L 1206
R19, R30: 150; Yageo RC_L 1206
R29, R32: 180; Yageo RC_L 1206
RV1: ERZV10D201; Panasonic ERZV10D201
U4: MOC3062M; DIP-6_W7.62mm

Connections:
+3.3V: D12.2 (A), R29.1; also elsewhere on the board
/Zero Cross Switch 1/DS: R32.2; also elsewhere on the board
GND: Q6.3 (E); also elsewhere on the board
unnamed: C2.1, R3.1, R19.1
unnamed: C2.2, D5.1 (A1), J2.2, R8.2, RV1.2
unnamed: D5.2 (A2), J2.1, R3.2, RV1.1
unnamed: D5.3 (G), R8.1, U4.4
unnamed: D12.1 (K), R30.2
unnamed: Q6.1 (B), R32.1
unnamed: Q6.2 (C), Q6.4 (C), R30.1, U4.2
unnamed: R19.2, U4.6
unnamed: R29.2, U4.1

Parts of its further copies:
C3: 22n; TDK B32682A4223
D6: T1635-600G; ST MIcroelectronics T16xx
D13: LED; Lite On LTST-C150
J3: ZC_SW; TerminalBlock_bornier-2_P5.08mm
Q7: PZT3904; SOT-223
R4: 50; Yageo RC_L 1218
R9: 390; Yageo RC_L 1206
R20, R31: 150; Yageo RC_L 1206
R33, R34: 180; Yageo RC_L 1206
RV2: ERZV10D201; Panasonic ERZV10D201
U5: MOC3062M; DIP-6_W7.62mm

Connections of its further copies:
+3.3V: D13.2 (A), R33.1; also elsewhere on the board
/Zero Cross Switch 2/DS: R34.2; also elsewhere on the board
GND: Q7.3 (E); also elsewhere on the board
unnamed: C3.1, R4.1, R20.1
unnamed: C3.2, D6.1 (A1), J3.2, R9.2, RV2.2
unnamed: D6.2 (A2), J3.1, R4.2, RV2.1
unnamed: D6.3 (G), R9.1, U5.4
unnamed: D13.1 (K), R31.2
unnamed: Q7.1 (B), R34.1
unnamed: Q7.2 (C), Q7.4 (C), R31.1, U5.2
unnamed: R20.2, U5.6
unnamed: R33.2, U5.1

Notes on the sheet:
Zero Cross Switching

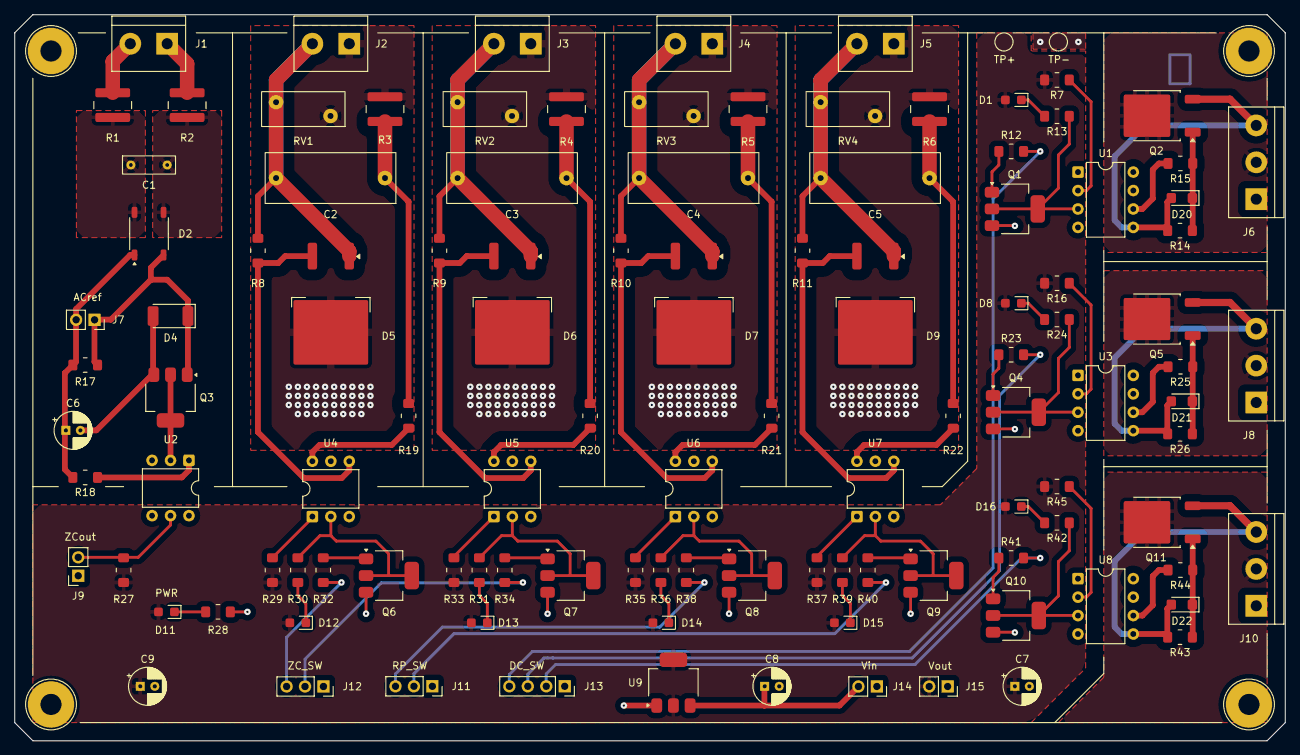
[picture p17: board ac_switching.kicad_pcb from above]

Board: 2 copper layers, 175.0 x 100.0 mm, 114 parts (0 on the bottom side), 84 nets.

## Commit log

2025-03-12 initial circuit schematic with sources
    [ac_switching.kicad_pcb, ac_switching.kicad_sch]
2025-03-13 footprint work started
    [ac_switching.kicad_sch]
2025-03-14 updated to pcb and footprints
    [ac_switching.kicad_sch]
2025-03-17 footprint attached and 2 channels done
    [ac_switching.kicad_pcb, ac_switching.kicad_sch]
2025-03-17 PCB completed
    [ac_switching.kicad_pcb, ac_switching.kicad_sch]
2025-03-18 PCB complete
    [ac_switching.kicad_pcb, ac_switching.kicad_sch]
2025-03-18 changes
    varistor replacement, cleaning up the layout and traces
    [ac_switching.kicad_pcb, ac_switching.kicad_sch]
2025-03-18 Circuit Schematic updated
    [ac_switching.kicad_pcb]
2025-03-19 increased the trace width and trace clearance.
    [ac_switching.kicad_pcb]
2025-03-19 Production ready
    [BOM.csv, ac_switching.kicad_pcb, ac_switching.kicad_sch]
2025-03-21 minor PCB fix
    [ac_switching.kicad_pcb]
2025-03-21 GERBER updated
2025-03-21 Merged zero crossing circuit
    [ac_switching.kicad_sch, dc_power.kicad_sch, rp_switching.kicad_sch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]
2025-03-26 DC Switching Schematic complete
    [ac_switching.kicad_sch, dc_power.kicad_sch, dc_switching.kicad_sch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]
2025-03-27 PCB updates
    [ac_switching.kicad_pcb, ac_switching.kicad_sch, dc_power.kicad_sch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]
2025-03-27 pcb progress
    [ac_switching.kicad_pcb, ac_switching.kicad_sch]
2025-03-28 PCB progress
    [ac_switching.kicad_pcb, ac_switching.kicad_sch, dc_power.kicad_sch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]
2025-03-31 Data Sheet added
    PCB complete, Final Footprint checks are pending
    [ac_switching.kicad_pcb, ac_switching.kicad_sch, dc_switching.kicad_sch]
2025-03-31 some minor changes to the PCB after DFM
    [ac_switching.kicad_pcb, dc_switching.kicad_sch]
2025-03-31 Production Version
    [BOM.csv, ac_switching.kicad_pcb, ac_switching.kicad_sch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]
2025-04-01 BOM added
    [BOM.csv, ac_switching.kicad_pcb, ac_switching.kicad_sch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]
2025-04-01 Schematic Update
    [ac_switching.kicad_pcb, ac_switching.kicad_sch, dc_power.kicad_sch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]
2025-04-01 BOM update
    [BOM.csv]
